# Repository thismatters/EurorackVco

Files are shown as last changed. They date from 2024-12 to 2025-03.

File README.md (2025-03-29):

# Voltage Controlled Oscillator

A Voltage Contolled Oscillator (VCO) is the backbone module for subtractive synthesis. It generates an audio signal which can then be shaped by myriad filters and amplifiers. Without a VCO you don't have a synth.

The circuit here is based on the [Yusynth VCO](https://yusynth.net/Modular/EN/VCO/index.html) with minor tweaks to make it more Eurorack friendly. The changes I've made are thus:
* Selected resistors appropriate for +/-12V rails,
* Added polarity protection so that a backward power header doesn't fry anything (twin series schotty diodes: BAT54SL),
* Selected a modern dual NPN diode package for the exponential converter,
* Full surface mount design,
* Toggle switch on front face for sync hardness.

The Yusynth page is a treasure trove of information about this circuit that I am too amateur to claim as my own; please read that outstanding page before using this circuit. The page provides several other implementations of the circuit that you may find suitable.

The KiCAD project here uses the library/footprints [found in my companion repo](https://github.com/thismatters/EurorackKiCAD).

## Width

10hp on a standard 3U rack.

## Inputs

This VCO features dual inputs for 1V/oct, Linear FM, and Exponential FM, Sync, and PWM. A toggle switch on the front face allows the player to set sync hardness. Two potentiometers allow the setting of frequency offset: coarse and fine. Two potentiometers are devoted to level for each of the frequency modulators (linear and exponential). Another pair of potentiometers gives control over (inherent) pulse width and PWM input level.

## Outputs

Four wave shapes are simultaneously available:
* Sine
* Triangle
* Saw (falling)
* Square

## Fiddly bits

Three 100kOhm resistors (R3, R4, R5) should be selected to within 0.1% tolerance (of each other) for good input tracking.

Likewise, two diodes (D5 and D6) ought to be selected which have a closely matched bias voltage in order to ensure a good sine wave symmetry. Testing SMD diodes for bias voltage is no small feat, so I didn't really bother doing this on my test circuits and first printed boards and they seemed fine. I hasten to bet that manufacturing processes have improved to the extent that manual matching is no longer relevant; but that could also just be a justification for laziness!

The schematic shows an OPA2134, however the original circuit calls for an OPA2137. The OPA2134 is a higher quality chip for sound applications, but it is also more expensive and was out of stock when I went to order; the OPA2137 is a suitable alternative.

The schematic calls for a `thermally_coupled_transistor_pair`; this is actually two components arranged carefully together. First a dual NPN transistor array (BCM847), then a thermco resistor which is nestled directly atop the transistor array package and the couple are blanketed in thermal grease so that the two components stay close to the same temperature.

## Adjustment

You'll need an oscilloscope, a CV keyboard, and ideally a tuner.

### Waveshape

1. Set the frequency potentiometers to their middle positions, set the FM and PWM level knobs to minimum (counterclockwise), and the PW knob to the middle position.
1. Connect the sawtooth output to the oscilloscope.
1. Power on the circuit.
1. Adjust RV10 until the sawtooth fills the full covers 10V from peak to peak (no horizontal line at top or bottom).
1. Adjust RV9 until the sawtooth is centered about 0V. (You may have to revisit RV10 to get this perfect; before moving on the saw wave should fill the +/-5V range)
1. Connect the triangle output to the oscilloscope.
1. Adjust RV9 some more to get the triangle shape just right.
1. Adjust RV11 until the triangle is centered around 0V. (You may have to revisit RV10 to get this perfect)
1. Connect the sine output to the oscilloscope.
1. The sine wave ought to look about right, but you may adjust RV9, RV11 (and possibly RV10) to hone this.

### Volt/Octave Tracking

1. Connect the CV source to the 1V/oct input, set the CV to 0V. If you're using a keyboard for this, hit C0.
1. Connect your tuner to the sine output.
1. Set CV to 0V, adjust the frequency knobs (coarse, then fine) until the tuner shows A1* (55Hz), then set the CV to 1V (press C1).
1. If the tuner shows A2 (110Hz) then you're all set, move on to the next step. Otherwise, if the pitch is sharp (>110Hz) adjust RV8 so that the pitch goes sharper (if flat go flatter)! Now go back to the prior step.
1. Repeat the prior _two_ steps this time jumping an additional octave. Once you've worked through all the octaves you have available then you're done!

| Tone | Frequency |
|---|---|
| A1 | 55 Hz |
| A2 | 110 Hz  |
| A3 | 220 Hz  |
| A4 | 440 Hz  |
| A5 | 880 Hz  |
| A6 | 1760 Hz |
| A7 | 3520 Hz |
| A8 | 7040 Hz |

\* A1 was chosen because it has a nice round number for a frequency which makes it easy to dial in on an oscilloscope. If you have a tuner use whatever pitch you like.

### Tuning

1. Disconnect all inputs from circuit.
1. Connect the tuner to the sine output.
1. Set the coarse frequency knob to the fully counterclockwise position (0), set the fine frequency knob to the middle position (0).
1. Connect a CV keyboard to the 1v/oct input, then press A3 (220Hz).
1. Adjust RV6 until the frequency is 220Hz.

## Vendors

There are part numbers in the [BOM](vco.csv) for many of the parts (not for basic passives though) at the following vendors:

* [Mouser](https://www.mouser.com): Needs no introduction. Get your ICs from here (or [digikey](https://www.digikey.com)).
* [Tayda Electronics](https://www.taydaelectronics.com/): Good supplier for passive components; audio jacks, and potentiometers. Their audio jacks are slightly smaller than the thonkiconn from thonk.
* [Thonk](https://www.thonk.co.uk/): The only place I've found tempco resistors for sale! You're looking for the 1k resistor, their store doesn't support part number searches. These are apparently sold out forever and no longer manufactured... I'll look around for alternatives, and experiment with omitting that resistor...
* [Love My Switches](https://lovemyswitches.com/): Has [really good knobs](https://lovemyswitches.com/anodized-aluminum-knob-the-lo-fi-1-4-smooth-shaft-12-5mm-od/) to go on those potentiometers!
* [OSHPark](https://oshpark.com/): Fast and (relatively) cheap PCB manufacturer. [The V1 circuit](https://oshpark.com/shared_projects/FmhO6zEO) works great, but you may have a hard time finding the 1K thermco resistor.

## Changelog

### v1
- first draft

### v2
- Added polarity protection,
- bigger holes for toggle switch footprint,
- reorganized board for easier trace routing,
- updated design language,
- narrowed by 2hp,
- changed some resistor values for more consistent +/-5V output,

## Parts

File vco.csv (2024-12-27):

# | Reference | Qty | Value | Footprint | DNP | Vendor | PartNum
1 | C1, C11, C13 | 3 | 47p | Capacitor_SMD:C_0805_2012Metric
2 | C2, C3 | 2 | 22u 50V | Capacitor_THT:CP_Radial_D5.0mm_P2.50mm
3 | C4 | 1 | 100p | Capacitor_SMD:C_0805_2012Metric
4 | C5 | 1 | 220p | Capacitor_SMD:C_0805_2012Metric
5 | C6, C7, C8, C9, C10 | 5 | 100n | Capacitor_SMD:C_0805_2012Metric
6 | C12 | 1 | 10p | Capacitor_SMD:C_0805_2012Metric
7 | D1, D2, D3, D4, D5, D6 | 6 | 1N4148 | Diode_SMD:D_SOD-323_HandSoldering
8 | D7, D8 | 2 | D_Dual_Series_AKC | Package_TO_SOT_SMD:SOT-23 |  | Mouser | 863-BAT54SLT1G
9 | J1 | 1 | EXP FM | Eurorack:AudioJack2_Tayda_A-2566 |  | Tayda | A-2566
10 | J2, J3 | 2 | 1V/OCT | Eurorack:AudioJack2_Tayda_A-2566 |  | Tayda | A-2566
11 | J4 | 1 | LIN FM | Eurorack:AudioJack2_Tayda_A-2566 |  | Tayda | A-2566
12 | J5 | 1 | PWM | Eurorack:AudioJack2_Tayda_A-2566 |  | Tayda | A-2566
13 | J6 | 1 | SYNC | Eurorack:AudioJack2_Tayda_A-2566 |  | Tayda | A-2566
14 | J7 | 1 | Sine | Eurorack:AudioJack2_Tayda_A-2566 |  | Tayda | A-2566
15 | J8 | 1 | Saw | Eurorack:AudioJack2_Tayda_A-2566 |  | Tayda | A-2566
16 | J9 | 1 | Triangle | Eurorack:AudioJack2_Tayda_A-2566 |  | Tayda | A-2566
17 | J10 | 1 | Square | Eurorack:AudioJack2_Tayda_A-2566 |  | Tayda | A-2566
18 | J11 | 1 | Conn_02x05_Odd_Even | Eurorack:PinHeader_2x05_P2.54mm_Vertical |  | Tayda | A-2939
19 | Q1 | 1 | MMBFJ113 | Package_TO_SOT_SMD:SOT-23 |  | Mouser | 512-MMBFJ113
20 | R1 | 1 | 68K | Resistor_SMD:R_0805_2012Metric
21 | R2, R10, R38 | 3 | 47K | Resistor_SMD:R_0805_2012Metric
22 | R3, R4, R5, R15, R16, R20, R23, R30, R32, R35, R36, R37, R41 | 13 | 100K | Resistor_SMD:R_0805_2012Metric
23 | R6 | 1 | 3M3 | Resistor_SMD:R_0805_2012Metric
24 | R7, R27 | 2 | 220K | Resistor_SMD:R_0805_2012Metric
25 | R8, R34 | 2 | 470K | Resistor_SMD:R_0805_2012Metric
26 | R9, R14 | 2 | 27K | Resistor_SMD:R_0805_2012Metric
27 | R11, R25 | 2 | 33K | Resistor_SMD:R_0805_2012Metric
28 | R12, R13 | 2 | 10 | Resistor_SMD:R_0805_2012Metric
29 | R17, R19, R26 | 3 | 1M | Resistor_SMD:R_0805_2012Metric
30 | R18, R22, R48 | 3 | 22K | Resistor_SMD:R_0805_2012Metric
31 | R21, R24, R28, R29, R33, R39 | 6 | 10K | Resistor_SMD:R_0805_2012Metric
32 | R31, R45 | 2 | 180K | Resistor_SMD:R_0805_2012Metric
33 | R40 | 1 | 8.2K | Resistor_SMD:R_0805_2012Metric
34 | R42, R47 | 2 | 150K | Resistor_SMD:R_0805_2012Metric
35 | R43, R44, R46, R51 | 4 | 1K | Resistor_SMD:R_0805_2012Metric
36 | R49 | 1 | 1.2K | Resistor_SMD:R_0805_2012Metric
37 | R50 | 1 | 15K | Resistor_SMD:R_0805_2012Metric
38 | RV1, RV2, RV3, RV4, RV5, RV7 | 6 | B100K | Eurorack:Potentiometer_RV16AF-41-15R1 |  | Tayda | A-2963
39 | RV6 | 1 | 250K | Potentiometer_THT:Potentiometer_Bourns_3296W_Vertical |  | Tayda | A-310
40 | RV8 | 1 | 25K | Potentiometer_THT:Potentiometer_Bourns_3296W_Vertical |  | Tayda | A-595
41 | RV9 | 1 | 100K | Potentiometer_THT:Potentiometer_Bourns_3296W_Vertical
42 | RV10 | 1 | 100K | Potentiometer_THT:Potentiometer_Bourns_3296W_Vertical |  | Tayda | A-587
43 | RV11 | 1 | 50K | Potentiometer_THT:Potentiometer_Bourns_3296W_Vertical |  | Tayda | A-598
44 | SW1 | 1 | Sync Mode | Eurorack:Switch_SPDT_Tayda_A-5751 |  | Tayda | A-5751
45 | U1, U6 | 2 | TL074 | Package_SO:SOIC-14_3.9x8.7mm_P1.27mm |  | Mouser | 595-TL074CDR
46 | U2 | 1 | OPA2134 | Package_SO:SO-8_3.9x4.9mm_P1.27mm |  | Mouser | 595-OPA2134UA/2K5
47 | U3 | 1 | L78L12_SO8 | Package_SO:SOIC-8_3.9x4.9mm_P1.27mm |  | Mouser | 863-NCV78L12ABDR2G
48 | U4 | 1 | L79L12_SO8 | Package_SO:SOIC-8_3.9x4.9mm_P1.27mm |  | Mouser | 863-MC79L12ABDR2G
49 | U5 | 1 | thermally_coupled_transistor_pair | Eurorack:SOT457+thermco_resistor |  | Mouser --and-- Thonk | 771-BCM847DS135 --and-- LT16S102F33
50 | U7 | 1 | LM311 | Package_SO:SOIC-8_3.9x4.9mm_P1.27mm |  | Mouser | 863-LM311DR2G

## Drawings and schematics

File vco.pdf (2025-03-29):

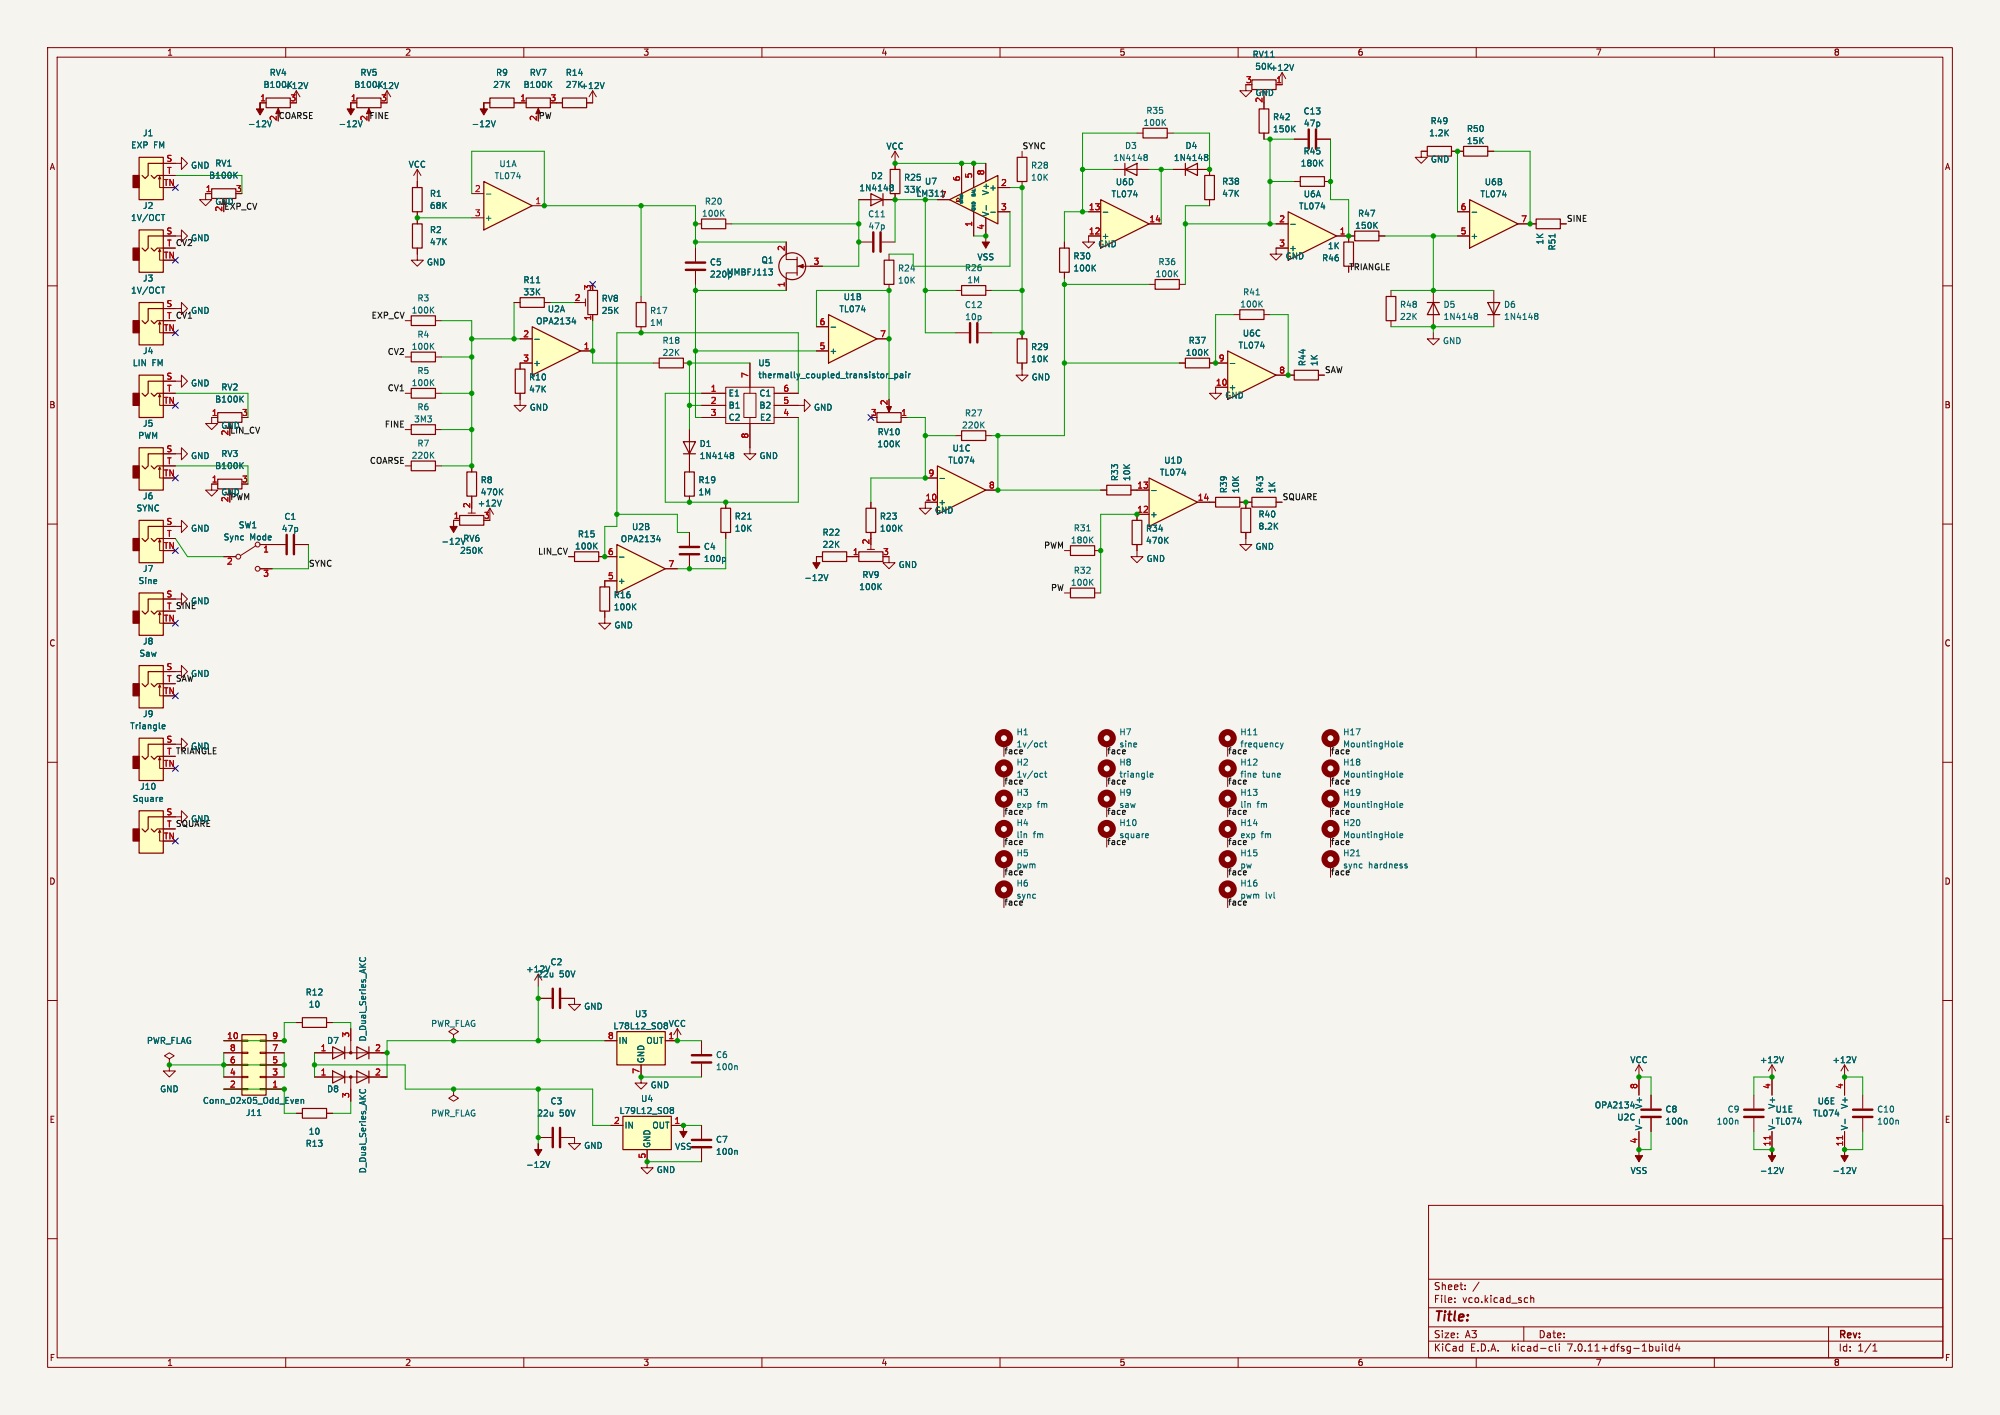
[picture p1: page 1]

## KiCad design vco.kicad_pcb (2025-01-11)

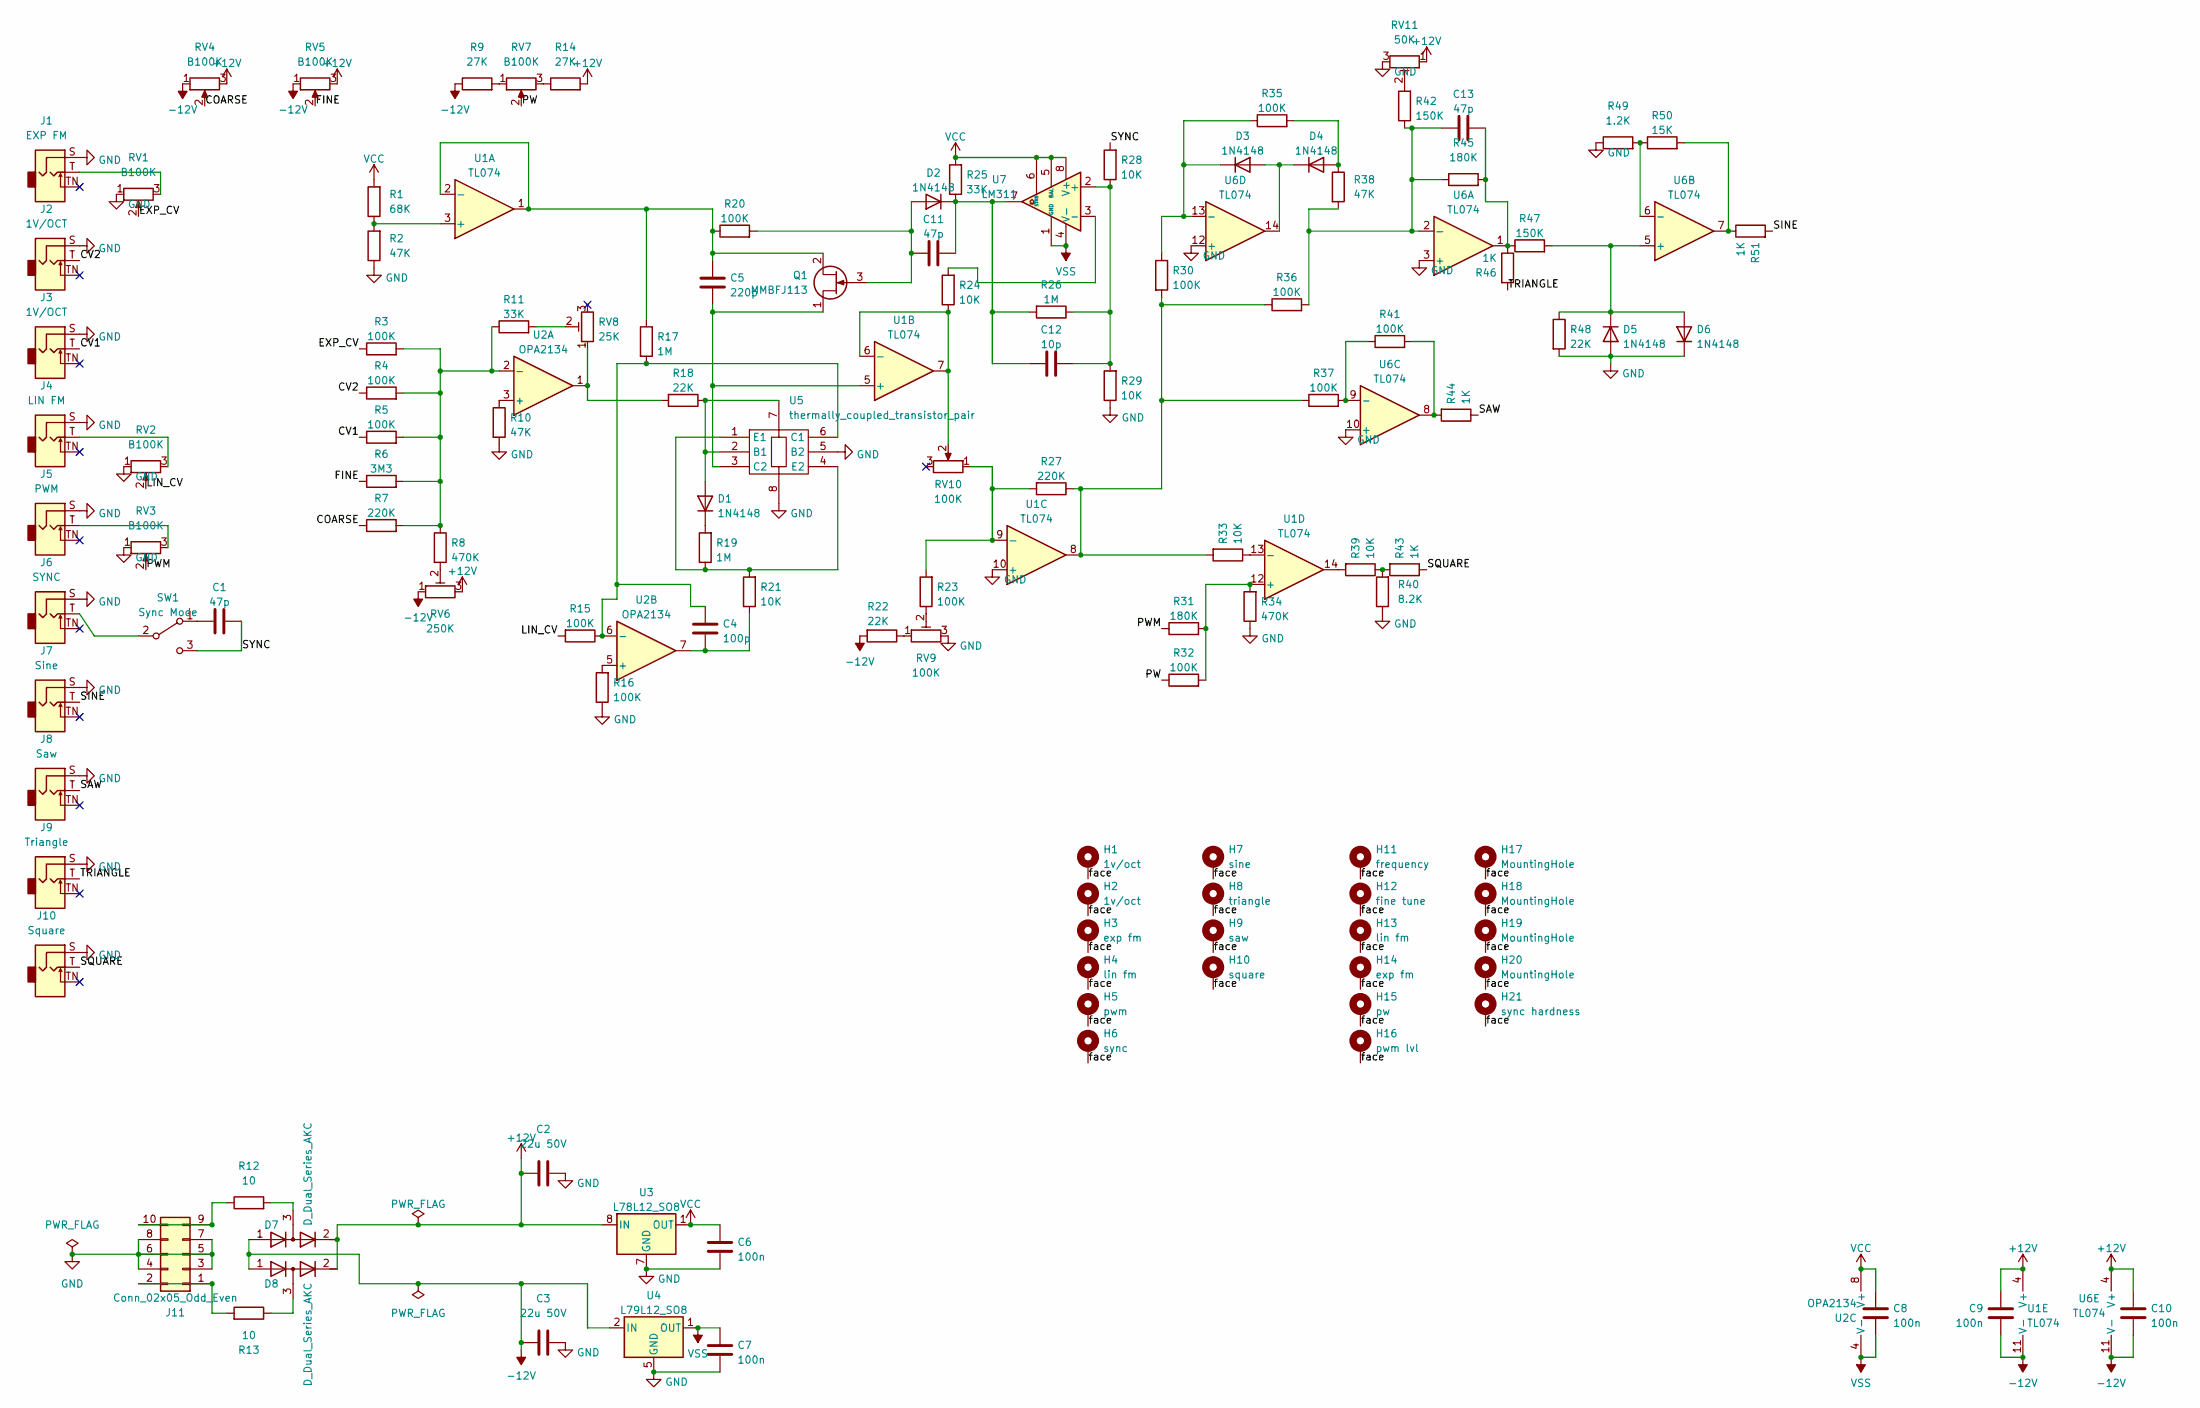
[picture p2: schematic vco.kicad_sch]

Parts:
C1, C11, C13: 47p; C_0805_2012Metric
C2, C3: 22u 50V; CP_Radial_D5.0mm_P2.50mm
C4: 100p; C_0805_2012Metric
C5: 220p; C_0805_2012Metric
C6, C7, C8, C9, C10: 100n; C_0805_2012Metric
C12: 10p; C_0805_2012Metric
D1, D2, D3, D4, D5, D6: 1N4148; D_SOD-323_HandSoldering
D7, D8: D_Dual_Series_AKC; SOT-23; PartNum 863-BAT54SLT1G
H1, H2: 1v/oct; Mech-AudioJack-Hole-Input-Voct
H3: exp fm; Mech-AudioJack-Hole-Input-CV
H4: lin fm; Mech-AudioJack-Hole-Input-CV
H5: pwm; Mech-AudioJack-Hole-Input-CV
H6: sync; Mech-AudioJack-Hole-Input-Clock
H7: sine; Mech-AudioJack-Hole-Output
H8: triangle; Mech-AudioJack-Hole-Output
H9: saw; Mech-AudioJack-Hole-Output
H10: square; Mech-AudioJack-Hole-Output
H11: frequency; Mech-Potentiometer-Hole_level
H12: fine tune; Mech-Potentiometer-Hole_pan
H13: lin fm; Mech-Potentiometer-Hole_level
H14: exp fm; Mech-Potentiometer-Hole_level
H15: pw; Mech-Potentiometer-Hole_pan
H16: pwm lvl; Mech-Potentiometer-Hole_level
H17, H18, H19, H20: MountingHole; Mech-MountingHole
H21: sync hardness; Mech-2M_Switch-Hole
J1: EXP FM; AudioJack2_Tayda_A-2566; PartNum A-2566
J2, J3: 1V/OCT; AudioJack2_Tayda_A-2566; PartNum A-2566
J4: LIN FM; AudioJack2_Tayda_A-2566; PartNum A-2566
J5: PWM; AudioJack2_Tayda_A-2566; PartNum A-2566
J6: SYNC; AudioJack2_Tayda_A-2566; PartNum A-2566
J7: Sine; AudioJack2_Tayda_A-2566; PartNum A-2566
J8: Saw; AudioJack2_Tayda_A-2566; PartNum A-2566
J9: Triangle; AudioJack2_Tayda_A-2566; PartNum A-2566
J10: Square; AudioJack2_Tayda_A-2566; PartNum A-2566
J11: Conn_02x05_Odd_Even; PinHeader_2x05_P2.54mm_Vertical; PartNum A-2939
Q1: MMBFJ113; SOT-23; PartNum 512-MMBFJ113
R1: 68K; R_0805_2012Metric
R2, R10, R38: 47K; R_0805_2012Metric
R3, R4, R5, R15, R16, R20, R23, R30, R32, R35, R36, R37, R41: 100K; R_0805_2012Metric
R6: 3M3; R_0805_2012Metric
R7, R27: 220K; R_0805_2012Metric
R8, R34: 470K; R_0805_2012Metric
R9, R14: 27K; R_0805_2012Metric
R11, R25: 33K; R_0805_2012Metric
R12, R13: 10; R_0805_2012Metric
R17, R19, R26: 1M; R_0805_2012Metric
R18, R22, R48: 22K; R_0805_2012Metric
R21, R24, R28, R29, R33, R39: 10K; R_0805_2012Metric
R31, R45: 180K; R_0805_2012Metric
R40: 8.2K; R_0805_2012Metric
R42, R47: 150K; R_0805_2012Metric
R43, R44, R46, R51: 1K; R_0805_2012Metric
R49: 1.2K; R_0805_2012Metric
R50: 15K; R_0805_2012Metric
RV1, RV2, RV3, RV4, RV5, RV7: B100K; Potentiometer_RV16AF-41-15R1; PartNum A-2963
RV6: 250K; Potentiometer_Bourns_3296W_Vertical; PartNum A-310
RV8: 25K; Potentiometer_Bourns_3296W_Vertical; PartNum A-595
RV9: 100K; Potentiometer_Bourns_3296W_Vertical
RV10: 100K; Potentiometer_Bourns_3296W_Vertical; PartNum A-587
RV11: 50K; Potentiometer_Bourns_3296W_Vertical; PartNum A-598
SW1: Sync Mode; Switch_SPDT_Tayda_A-5751; PartNum A-5751
U1, U6: TL074; SOIC-14_3.9x8.7mm_P1.27mm; PartNum 595-TL074CDR
U2: OPA2134; SO-8_3.9x4.9mm_P1.27mm; PartNum 595-OPA2134UA/2K5
U3: L78L12_SO8; SOIC-8_3.9x4.9mm_P1.27mm; PartNum 863-NCV78L12ABDR2G
U4: L79L12_SO8; SOIC-8_3.9x4.9mm_P1.27mm; PartNum 863-MC79L12ABDR2G
U5: thermally_coupled_transistor_pair; SOT457+thermco_resistor; PartNum 771-BCM847DS135 --and-- LT16S102F33
U7: LM311; SOIC-8_3.9x4.9mm_P1.27mm; PartNum 863-LM311DR2G

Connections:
+12V: C2.1, C9.1, C10.1, D7.2 (K), D8.2 (K), R14.2, RV4.3, RV5.3, RV6.3, RV11.1, U1.4 (V+), U3.8 (IN), U6.4 (V+)
-12V: C3.1, C9.2, C10.2, D7.1 (A), D8.1 (A), R9.1, R22.2, RV4.1, RV5.1, RV6.1, U1.11 (V-), U4.2 (IN), U4.3 (IN), U4.6 (IN), U4.7 (IN), U6.11 (V-)
/COARSE: R7.1, RV4.2
/CV1: J3.T, R5.1
/CV2: J2.T, R4.1
/EXP_CV: R3.1, RV1.2
/FINE: R6.1, RV5.2
/LIN_CV: R15.2, RV2.2
/PW: R32.1, RV7.2
/PWM: R31.1, RV3.2
/SAW: J8.T, R44.1
/SINE: J7.T, R51.2
/SQUARE: J10.T, R43.1
/SYNC: C1.1, R28.2, SW1.3 (C)
/TRIANGLE: J9.T, R46.2
/face: H1.1, H2.1, H3.1, H4.1, H5.1, H6.1, H7.1, H8.1, H9.1, H10.1, H11.1, H12.1, H13.1, H14.1, H15.1, H16.1, H17.1, H18.1, H19.1, H20.1, H21.1
GND: C2.2, C3.2, C6.2, C7.2, D5.2 (A), D6.1 (K), J1.S, J2.S, J3.S, J4.S, J5.S, J6.S, J7.S, J8.S, J9.S, J10.S, J11.3, J11.4, J11.5, J11.6, J11.7, J11.8, R2.1, R10.2, R16.1, R29.1, R34.1, R40.1, R48.2, R49.1, RV1.1, RV2.1, RV3.1, RV9.3, RV11.3, U1.10 (+), U3.2 (GND), U3.3 (GND), U3.6 (GND), U3.7 (GND), U4.5 (GND), U5.5 (B2), U5.8, U6.3 (+), U6.10 (+), U6.12 (+)
unnamed: C4.1, R21.1, U2.7
unnamed: C13.1, R45.2, R46.1, R47.1, U6.1
unnamed: D1.2 (A), R18.1, U5.2 (B1), U5.7
unnamed: D1.1 (K), R19.2
unnamed: C11.2, D2.2 (A), Q1.3 (G), R20.2
unnamed: C11.1, C12.2, D2.1 (K), R25.1, R26.2, U7.7
unnamed: D3.2 (A), D4.1 (K), U6.14
unnamed: D3.1 (K), R30.1, R35.1, U6.13 (-)
unnamed: D4.2 (A), R35.2, R38.1
unnamed: D5.1 (K), D6.2 (A), R47.2, R48.1, U6.5 (+)
unnamed: D7.3 (common), R12.2
unnamed: D8.3 (common), R13.1
unnamed: J1.T, RV1.3
unnamed: J4.T, RV2.3
unnamed: J5.T, RV3.3
unnamed: J11.1, J11.2, R13.2
unnamed: J11.9, J11.10, R12.1
unnamed: C5.1, Q1.1 (D), U1.5 (+), U5.3 (C2)
unnamed: C5.2, Q1.2 (S), R17.1, R20.1, U1.1, U1.2 (-)
unnamed: R8.2, RV6.2
unnamed: R9.2, RV7.1
unnamed: R11.2, RV8.2
unnamed: R14.1, RV7.3
unnamed: R18.2, RV8.1, U2.1
unnamed: R22.1, RV9.1
unnamed: R23.1, RV9.2
unnamed: R27.1, R30.2, R33.2, R36.1, R37.1, U1.8
unnamed: R39.1, R40.2, R43.2
unnamed: R39.2, U1.14
unnamed: R41.2, R44.2, U6.8
unnamed: R42.2, RV11.2
unnamed: R50.2, R51.1, U6.7
unnamed: C1.2, SW1.1 (A)
unnamed: J6.T, SW1.2 (B)
unnamed: R1.1, R2.2, U1.3 (+)
unnamed: R24.1, RV10.2, U1.6 (-), U1.7
unnamed: R23.2, R27.2, RV10.1, U1.9 (-)
unnamed: R31.2, R32.2, R34.2, U1.12 (+)
unnamed: R33.1, U1.13 (-)
unnamed: R10.1, U2.3 (+)
unnamed: R3.2, R4.2, R5.2, R6.2, R7.2, R8.1, R11.1, U2.2 (-)
unnamed: R16.2, U2.5 (+)
unnamed: C4.2, R15.1, R17.2, U2.6 (-), U5.6 (C1)
unnamed: R19.1, R21.2, U5.1 (E1), U5.4 (E2)
unnamed: C13.2, R36.2, R38.2, R42.1, R45.1, U6.2 (-)
unnamed: R49.2, R50.1, U6.6 (-)
unnamed: R37.2, R41.1, U6.9 (-)
unnamed: C12.1, R26.1, R28.1, R29.2, U7.2 (+)
unnamed: R24.2, U7.3 (-)
VCC: C6.1, C8.1, R1.2, R25.2, U2.8 (V+), U3.1 (OUT), U7.5 (BAL), U7.6 (STRB), U7.8 (V+)
VSS: C7.1, C8.2, U2.4 (V-), U4.1 (OUT), U7.1 (GND), U7.4 (V-)

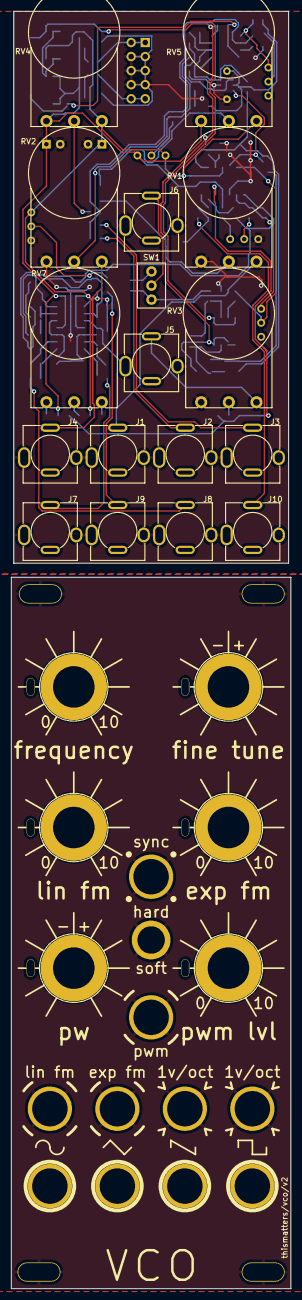
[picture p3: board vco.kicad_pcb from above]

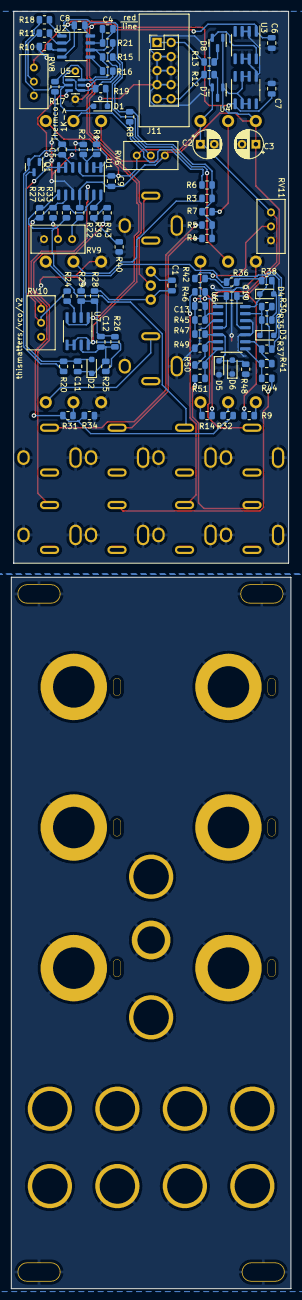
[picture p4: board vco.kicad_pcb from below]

Board: 2 copper layers, 50.5 x 230.7 mm, 124 parts (86 on the bottom side), 68 nets.

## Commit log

2023-02-15 checking all resistor values
    [vco.csv, vco.kicad_pcb, vco.kicad_sch]
2024-01-02 v2 ready for manu
    [vco.csv, vco.kicad_pcb, vco.kicad_sch]
2024-01-02 wrong part number
    [vco.csv, vco.kicad_sch]
2024-12-27 v2 just about ready for manu
    [vco.csv, vco.kicad_pcb, vco.kicad_sch]
2024-12-27 bom fixes
    [vco.csv, vco.kicad_pcb, vco.kicad_sch]
2024-12-27 more bom fixes
    [vco.csv, vco.kicad_pcb, vco.kicad_sch]
2024-12-27 use bigger potentiometers (i've got some)
    [vco.csv, vco.kicad_pcb, vco.kicad_sch]
2024-12-27 one last resistor value
    [vco.csv, vco.kicad_pcb, vco.kicad_sch]
2024-12-27 trimmer values
    [vco.csv, vco.kicad_pcb, vco.kicad_sch]
2025-01-11 pcb updated for v2
    [vco.kicad_pcb]
